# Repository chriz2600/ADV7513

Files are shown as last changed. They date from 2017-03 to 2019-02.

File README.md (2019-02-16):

# ADV7513

This is a small development board for the [Analog Devices ADV7513 HDMI Transmitter][ADV7513]. It's designed to be hand-soldered.
I also wrote some code for initialisation (via I2C) in verilog. This can be found as part of my [Dreamcast HDMI][DreamcastHDMI] project. 

[][oshparkorder]

[ADV7513]: http://www.analog.com/en/products/audio-video/analoghdmidvi-interfaces/analog-hdmidvi-display-interfaces/adv7513.html
[DreamcastHDMI]: https://github.com/chriz2600/DreamcastHDMI/tree/master/FPGA-CycloneIV-ADV7513

[oshparkorder]: https://oshpark.com/shared_projects/b1enkRm7
[oshpark]: https://oshpark.com/assets/badge-5b7ec47045b78aef6eb9d83b3bac6b1920de805e9a0c227658eac6e19a045b9c.png

### BOM

- `U1`: [ADV7513](http://www.analog.com/en/products/audio-video/analoghdmidvi-interfaces/analog-hdmidvi-display-interfaces/adv7513.html)

    This seems to be a little harder to get from an official distributor, if you are not an HDMI licensee. 
    
    You can get it from [Aliexpress](https://www.aliexpress.com/wholesale?SearchText=ADV7513)

- `U2`: [NCP1117DT33G](https://www.digikey.com/products/en?keywords=NCP1117DT33G)
- `U3`: [NCP1117DT18G](https://www.digikey.com/products/en?keywords=NCP1117DT18G)
- `J1`: [HDMI Connector](https://www.digikey.com/product-detail/en/amphenol-icc-fci/10029449-111RLF/609-4614-1-ND/2785376)
- `U4, U5, U6`: [TVS_DIODE](https://www.digikey.com/product-detail/en/diodes-incorporated/D5V0F4U10MR-13/D5V0F4U10MR-13DICT-ND/4473969)
- `C1, C7, C9, C11, C17, C18`: 10u (0805)
- `C2, C3, C4, C5, C6, C8, C10, C12, C13, C14, C15, C16`: 100n (0805)
- `R1, R2, R5, R6, R7, R8`: 2K (0805)
- `R3`: 887R (0805)
- `R4`: 10K (0805)
- `L1, L2, L3, L4`: 10u (1210)

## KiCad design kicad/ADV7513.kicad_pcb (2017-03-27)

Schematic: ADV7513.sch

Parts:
C1, C7, C9, C11, C17, C18: 10u; C_0805_HandSoldering
C2, C3, C4, C5, C6, C8, C10, C12, C13, C14, C15, C16: 100n; C_0805_HandSoldering
J1: HDMI; hdmi_new
L1, L2, L3, L4: 10u; R_1210_HandSoldering
P1: 5V; Pin_Header_Straight_1x02_Pitch2.54mm
P2: SYNC; Pin_Header_Straight_2x04_Pitch2.54mm
P3: I2C_INT; Pin_Header_Straight_1x04_Pitch2.54mm
P4: AUDIO; Pin_Header_Straight_2x08_Pitch2.54mm
P5: RED; Pin_Header_Straight_2x08_Pitch2.54mm
P6: GREEN; Pin_Header_Straight_2x08_Pitch2.54mm
P7: BLUE; Pin_Header_Straight_2x08_Pitch2.54mm
R1, R2, R5, R6, R7, R8: 2K; R_0805_HandSoldering
R3: 887R; R_0805_HandSoldering
R4: 10K; R_0805_HandSoldering
U1: ADV7513; HTQFP-64_1EP_10x10mm_Pitch0.5mm_ThermalPad3
U2: NCP1117DT33G; TO-252-2Lead
U3: NCP1117DT18G; TO-252-2Lead
U4, U5, U6: TVS_DIODE_3.3VWM_10VC_SMD; MSOP-10_3x3mm_Pitch0.5mm

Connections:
1V8: C2.1, C3.1, C4.1, C5.1, C18.1, L4.1, U1.1 (DVDD), U1.11 (DVDD), U1.31 (DVDD), U1.51 (DVDD)
3V3: C6.1, C17.1, L3.1, R5.1, R6.1, R7.1, U1.29 (DVDD_3V)
5V: C7.1, C8.1, J1.18, P1.2, R1.1, R2.1, U2.3, U6.4 (Ch2), U6.7 (NC)
AVDD_1V8: C11.1, C12.1, C13.1, C14.1, L2.1, U1.15 (AVDD), U1.19 (AVDD), U1.25 (AVDD)
DDCSCL: J1.15, R1.2, U1.33 (DDCSCL), U6.1 (Ch1), U6.10 (NC)
DDCSDA: J1.16, R2.2, U1.34 (DDCSDA), U6.2 (NC), U6.9 (Ch4)
GND: C1.2, C2.2, C3.2, C4.2, C5.2, C6.2, C7.2, C8.2, C9.2, C10.2, C11.2, C12.2, C13.2, C14.2, C15.2, C16.2, C17.2, C18.2, J1.0, J1.2, J1.5, J1.8, J1.11, J1.13, J1.14, J1.17, P1.1, P2.1, P2.3, P2.5, P2.7, P3.1, P4.1, P4.3, P4.5, P4.7, P4.9, P4.11, P4.13, P4.15, P5.1, P5.3, P5.5, P5.7, P5.9, P5.11, P5.13, P5.15, P6.1, P6.3, P6.5, P6.7, P6.9, P6.11, P6.13, P6.15, P7.1, P7.3, P7.5, P7.7, P7.9, P7.11, P7.13, P7.15, R3.2, R4.2, R8.2, U1.30 (CEC), U1.32 (CEC_CLK), U1.65 (PAD/GND), U2.1, U3.1, U4.8 (GND), U5.8 (GND), U6.8 (GND)
HPD: J1.19, R4.1, U1.16 (HPD), U6.5 (NC), U6.6 (Ch3)
unnamed: C9.1, C10.1, L3.2, U2.2, U3.3
unnamed: L1.2, L2.2, L4.2, U3.2
unnamed: P2.2, U1.63 (DE)
unnamed: P2.4, U1.64 (HSYNC)
unnamed: P2.6, U1.53 (CLK)
unnamed: P2.8, U1.2 (VSYNC)
unnamed: P3.2, R7.2, U1.28 (INT)
unnamed: P3.3, R6.2, U1.35 (SCL)
unnamed: P3.4, R5.2, U1.36 (SDA)
unnamed: P4.2, U1.3 (SPDIF)
unnamed: P4.4, U1.4 (MCLK)
unnamed: P4.6, U1.5 (I2S0)
unnamed: P4.8, U1.6 (I2S1)
unnamed: P4.10, U1.7 (I2S2)
unnamed: P4.12, U1.8 (I2S3)
unnamed: P4.14, U1.9 (SCLK)
unnamed: P4.16, U1.10 (LRCLK)
unnamed: P5.2, U1.37 (DATA23)
unnamed: P5.4, U1.38 (DATA22)
unnamed: P5.6, U1.39 (DATA21)
unnamed: P5.8, U1.40 (DATA20)
unnamed: P5.10, U1.41 (DATA19)
unnamed: P5.12, U1.42 (DATA18)
unnamed: P5.14, U1.43 (DATA17)
unnamed: P5.16, U1.44 (DATA16)
unnamed: P6.2, U1.45 (DATA15)
unnamed: P6.4, U1.46 (DATA14)
unnamed: P6.6, U1.47 (DATA13)
unnamed: P6.8, U1.48 (DATA12)
unnamed: P6.10, U1.49 (DATA11)
unnamed: P6.12, U1.50 (DATA10)
unnamed: P6.14, U1.52 (DATA9)
unnamed: P6.16, U1.54 (DATA8)
unnamed: P7.2, U1.55 (DATA7)
unnamed: P7.4, U1.56 (DATA6)
unnamed: P7.6, U1.57 (DATA5)
unnamed: P7.8, U1.58 (DATA4)
unnamed: P7.10, U1.59 (DATA3)
unnamed: P7.12, U1.60 (DATA2)
unnamed: P7.14, U1.61 (DATA1)
unnamed: P7.16, U1.62 (DATA0)
unnamed: R3.1, U1.14 (R_EXT)
unnamed: R8.1, U1.22 (PD)
PVDD_1V8: C1.1, C15.1, C16.1, L1.1, U1.12 (PVDD), U1.13 (BGVDD)
TX0+: J1.7, U1.21 (TX0+), U4.5 (NC), U4.6 (Ch3)
TX0-: J1.9, U1.20 (TX0-), U4.4 (Ch2), U4.7 (NC)
TX1+: J1.4, U1.24 (TX1+), U5.2 (NC), U5.9 (Ch4)
TX1-: J1.6, U1.23 (TX1-), U5.1 (Ch1), U5.10 (NC)
TX2+: J1.1, U1.27 (TX2+), U5.5 (NC), U5.6 (Ch3)
TX2-: J1.3, U1.26 (TX2-), U5.4 (Ch2), U5.7 (NC)
TXC+: J1.10, U1.18 (TXC+), U4.2 (NC), U4.9 (Ch4)
TXC-: J1.12, U1.17 (TXC-), U4.1 (Ch1), U4.10 (NC)

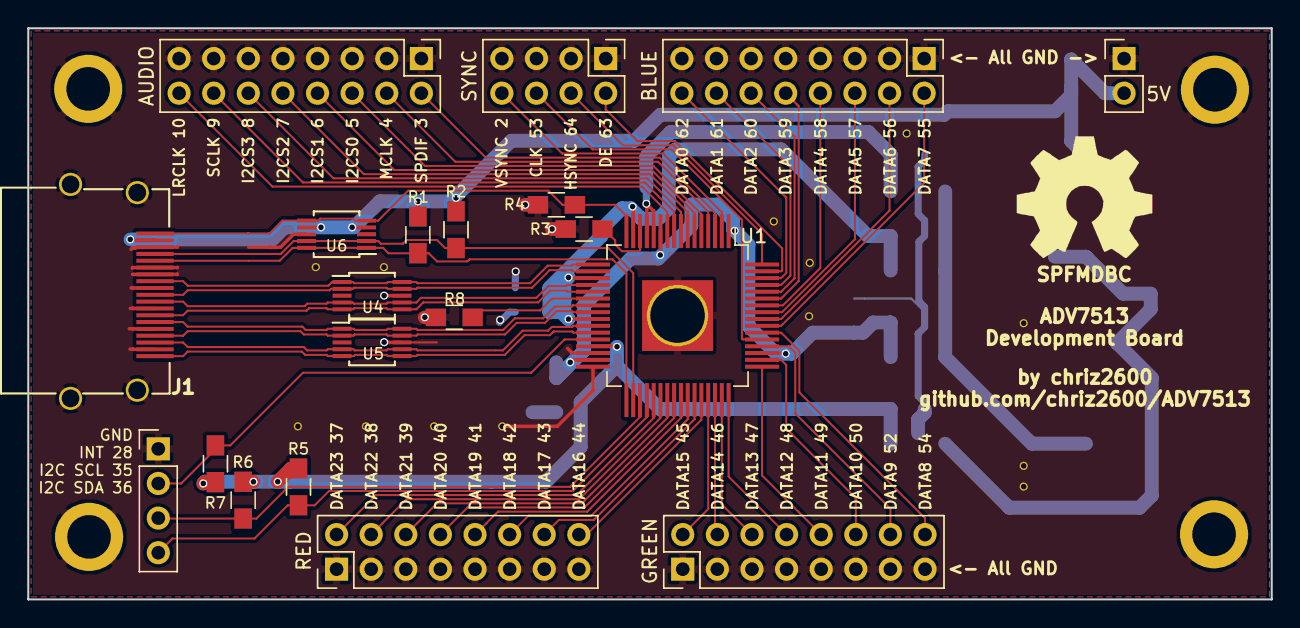
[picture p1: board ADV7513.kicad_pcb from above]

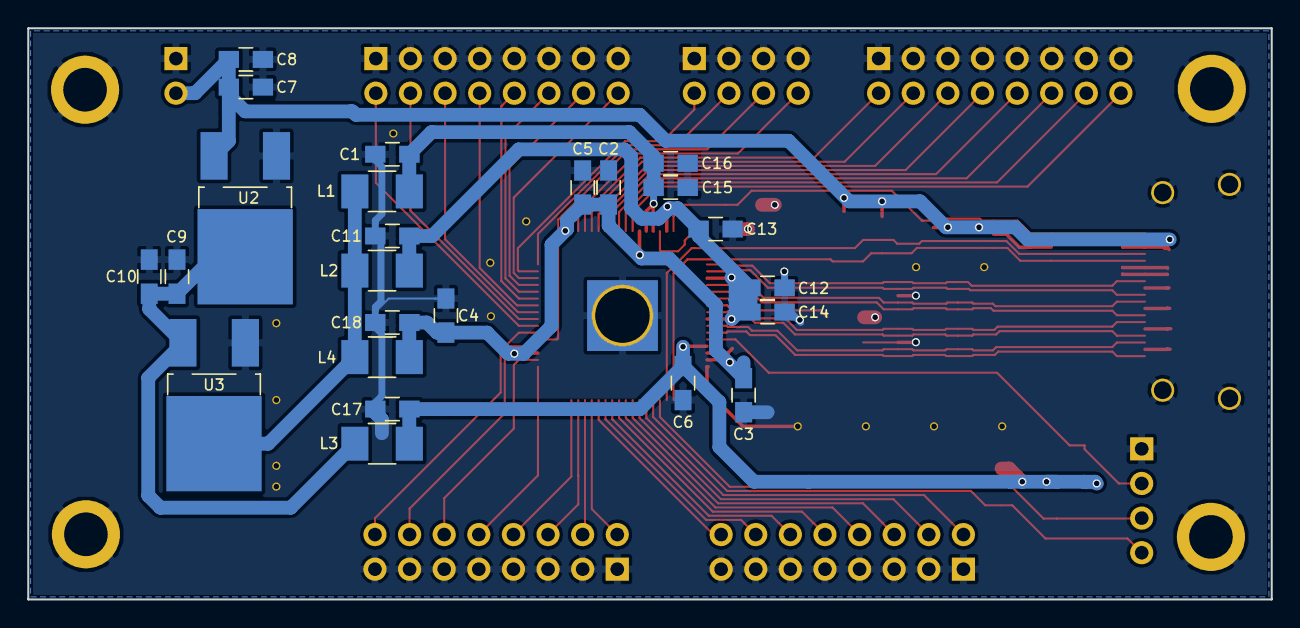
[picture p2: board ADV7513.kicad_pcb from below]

Board: 4 copper layers, 91.2 x 41.9 mm, 45 parts (24 on the bottom side), 60 nets.

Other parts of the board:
VAL: REF; OSHW-logo_10mm

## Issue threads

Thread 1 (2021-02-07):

Just a question of the success of this project ;o)

samowitsch, 2021-02-07:
I stumbled over this project searching information about the ADV7513.
But the information is rare. How was your success with the ADV7513
development board and how did you programm the ADV7513 over i2c?

Regards

chriz2600, 2021-02-07:
Luckily, you can get a lot of information from Analog directly without being an HDMI adopter: [Documentation](https://www.analog.com/en/products/adv7513.html#product-documentation)
That's probably the reason, why it's used in a lot of open source projects.
Seems like they removed the link to the programming guide recently, but it's still available on their [website](https://www.analog.com/media/en/technical-documentation/user-guides/ADV7513_Programming_Guide.pdf).
This contains all information to set it up via I2C. The linux driver for the ADV7511 (very similar to the ADV7513) is also a good starting point figuring out the I2C registers needed.
I successfully used it in several projects.

samowitsch, 2021-02-08:
Thx for your reply and the infos. Do you have one of your ADV7513
eval boards (populated?) that you dont need anymore? I would buy one ;o)

Regards from germany ^.^
Christian

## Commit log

2017-03-27 Initial import
    [ADV7513.kicad_pcb, ADV7513.sch]
2017-03-27 Ground HDMI connector shield
    [ADV7513.kicad_pcb]
2018-03-23 cleaned up libraries
    [ADV7513.sch]
2019-02-16 added bom
